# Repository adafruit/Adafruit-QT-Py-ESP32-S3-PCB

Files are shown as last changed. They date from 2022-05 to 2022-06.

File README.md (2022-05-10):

## Adafruit QT Py ESP32-S3 WiFi Dev Board PCB

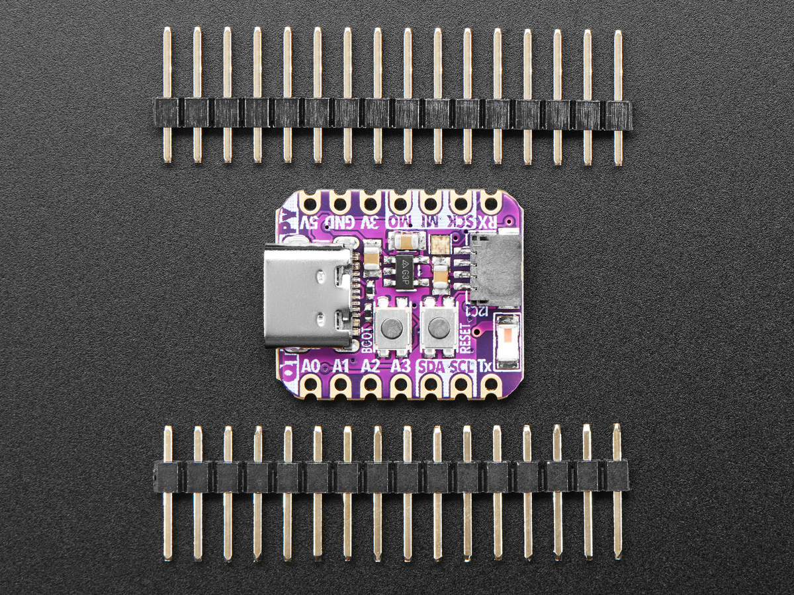
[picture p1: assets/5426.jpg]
<a href="http://www.adafruit.com/products/5426"><br/>
Click here to purchase one from the Adafruit shop</a>

PCB files for the Adafruit QT Py ESP32-S3 WiFi Dev Board. 

Format is EagleCAD schematic and board layout
* https://www.adafruit.com/product/5426

### Description

The ESP32-S3 has arrived in QT Py format - and what a great way to get started with this powerful new chip from Espressif! With dual 240 MHz cores, WiFi and BLE support, and native USB, this QT Py is great for powering your IoT projects.

The ESP32-S3 is a highly-integrated, low-power, 2.4 GHz Wi-Fi System-on-Chip (SoC) solution that now has WiFi and BLE support, built-in native USB as well as some other interesting new technologies like Time of Flight distance measurements. With its state-of-the-art power and RF performance, this SoC is an ideal choice for a wide variety of application scenarios relating to the Internet of Things (IoT), wearable electronics, and smart homes. 

With native USB and 8 MB Flash this board will let you upgrade your existing ESP32 projects. Native USB means it can act like a keyboard or a disk drive, and no external USB-to-Serial converter required. WiFi and BLE mean it's awesome for IoT projects.

OLEDs! Inertial Measurement Units! Sensors a-plenty. All plug-and-play thanks to the innovative chainable design: SparkFun Qwiic-compatible STEMMA QT connectors for the I2C bus so you don't even need to solder! Just plug in a compatible cable and attach it to your MCU of choice, and you’re ready to load up some software and measure some light. Seeed Grove I2C boards will also work with this adapter cable.

Pinout and shape are Seeed Xiao compatible, with castellated pads so you can solder it flat to a PCB. In addition to the QT connector, we also added an RGB NeoPixel (with controllable power pin to allow for ultra-low-power usage), a reset button (great for restarting your program or entering the bootloader), and a button on GPIO 0 for entering the ROM bootloader or for user input

The ESP32-S3 has a dual-core 240 MHz chip, so it is comparable to ESP32's dual-core. However, there is no Bluetooth Classic support, only Bluetooth LE. This chip is a great step up from the earlier ESP32-S2! This ESP32-S3 chip we are using on the QT Py comes with 8 MB flash and no PSRAM, but it does have 512KB of SRAM so its fine for use with CircuitPython support as long as massive buffers are not needed. It's also great for use in ESP-IDF or with Arduino support.

* Same size, form-factor, and pin-out as Seeed Xiao
* USB Type C connector - If you have only Micro B cables, this adapter will come in handy!
* ESP32-S3 Dual Core 240MHz Tensilica processor - the next generation of ESP32-Sx, with native USB so it can act like a keyboard/mouse, MIDI device, disk drive, etc!
* Comes with 8MB Flash, 512KB SRAM, no PSRAM
* Native USB supported by every OS - can be used in Arduino or CircuitPython as USB serial console, MIDI, Keyboard/Mouse HID, even a little disk drive for storing Python scripts.
* Can be used with Arduino IDE or CircuitPython
* Built-in RGB NeoPixel LED with power control to reduce quiescent power in deep sleep
* Battery input pads on underside with diode protection for external battery packs up to 6V input
* 13 GPIO pins:
    * 11 on breakout pads, 2 more on QT connector
    * 10 x 12-bit analog inputs (SPI high speed pads do not have analog inputs)
    * PWM outputs on any pin
    * Two I2C ports, one on the breakout pads, and another with STEMMA QT plug-n-play connector
    * Hardware UART
    * Hardware SPI on the high speed SPI peripheral pins
    * Hardware I2S on any pins
    * 5 x Capacitive Touch with no additional components required
* 3.3V regulator with 600mA peak output
* Light sleep at 2~4mA, deep sleep at ~70uA
* Reset switch for starting your project code over, boot 0 button for entering bootloader mode
* Really really small

### License

Adafruit invests time and resources providing this open source design, please support Adafruit and open-source hardware by purchasing products from [Adafruit](https://www.adafruit.com)!

Designed by Limor Fried/Ladyada for Adafruit Industries.

Creative Commons Attribution/Share-Alike, all text above must be included in any redistribution. 
See license.txt for additional details.

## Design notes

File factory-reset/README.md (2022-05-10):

## Factory Reset file - QT ESP32-S3 WiFi Dev Board

This is the factory reset file for the QT ESP32-S3 WiFi Dev Board.

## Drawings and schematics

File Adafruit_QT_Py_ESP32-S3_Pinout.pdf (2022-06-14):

# Adafruit QT Py ESP32S3

# https://www.adafruit.com/5426

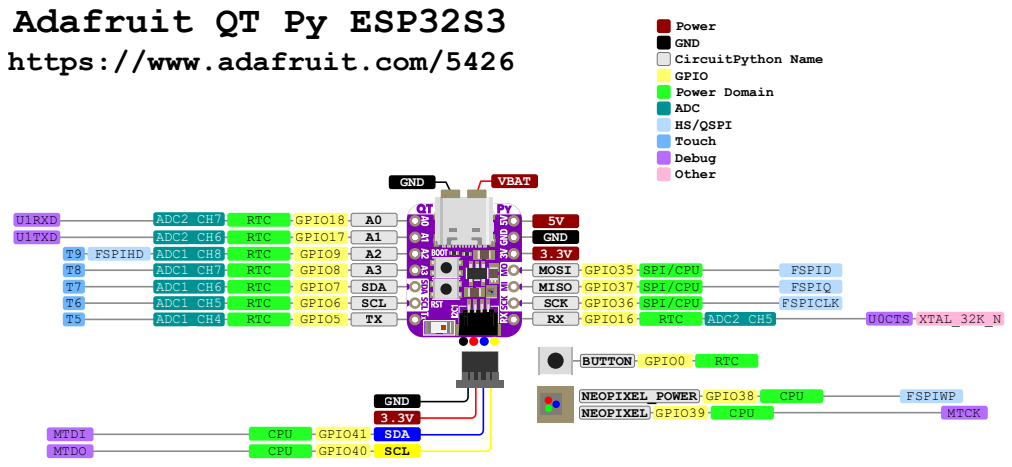
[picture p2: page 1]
U1RXD; ADC2_CH7 RTC GPIO18 A0; ADC1_CH4 RTC; GPIO5 TX; RX GPIO16 RTC ADC2_CH5; U0CTS XTAL_32K_N; GND 3.3V; MOSI GPIO35 SPI/CPU; FSPID; MISO GPIO37 SPI/CPU; FSPIQ; SCK GPIO36 SPI/CPU; FSPICLK; MTDI; CPU GPIO41; U1TXD; ADC2_CH6 RTC GPIO17 A1; T9 FSPIHD ADC1_CH8 RTC; GPIO9 A2; ADC1_CH7 RTC; GPIO8 A3; ADC1_CH6 RTC; GPIO7 SDA; ADC1_CH5 RTC; GPIO6 SCL; BUTTON GPIO0; RTC; NEOPIXEL_POWER GPIO38 CPU; FSPIWP; NEOPIXEL GPIO39 CPU; MTCK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

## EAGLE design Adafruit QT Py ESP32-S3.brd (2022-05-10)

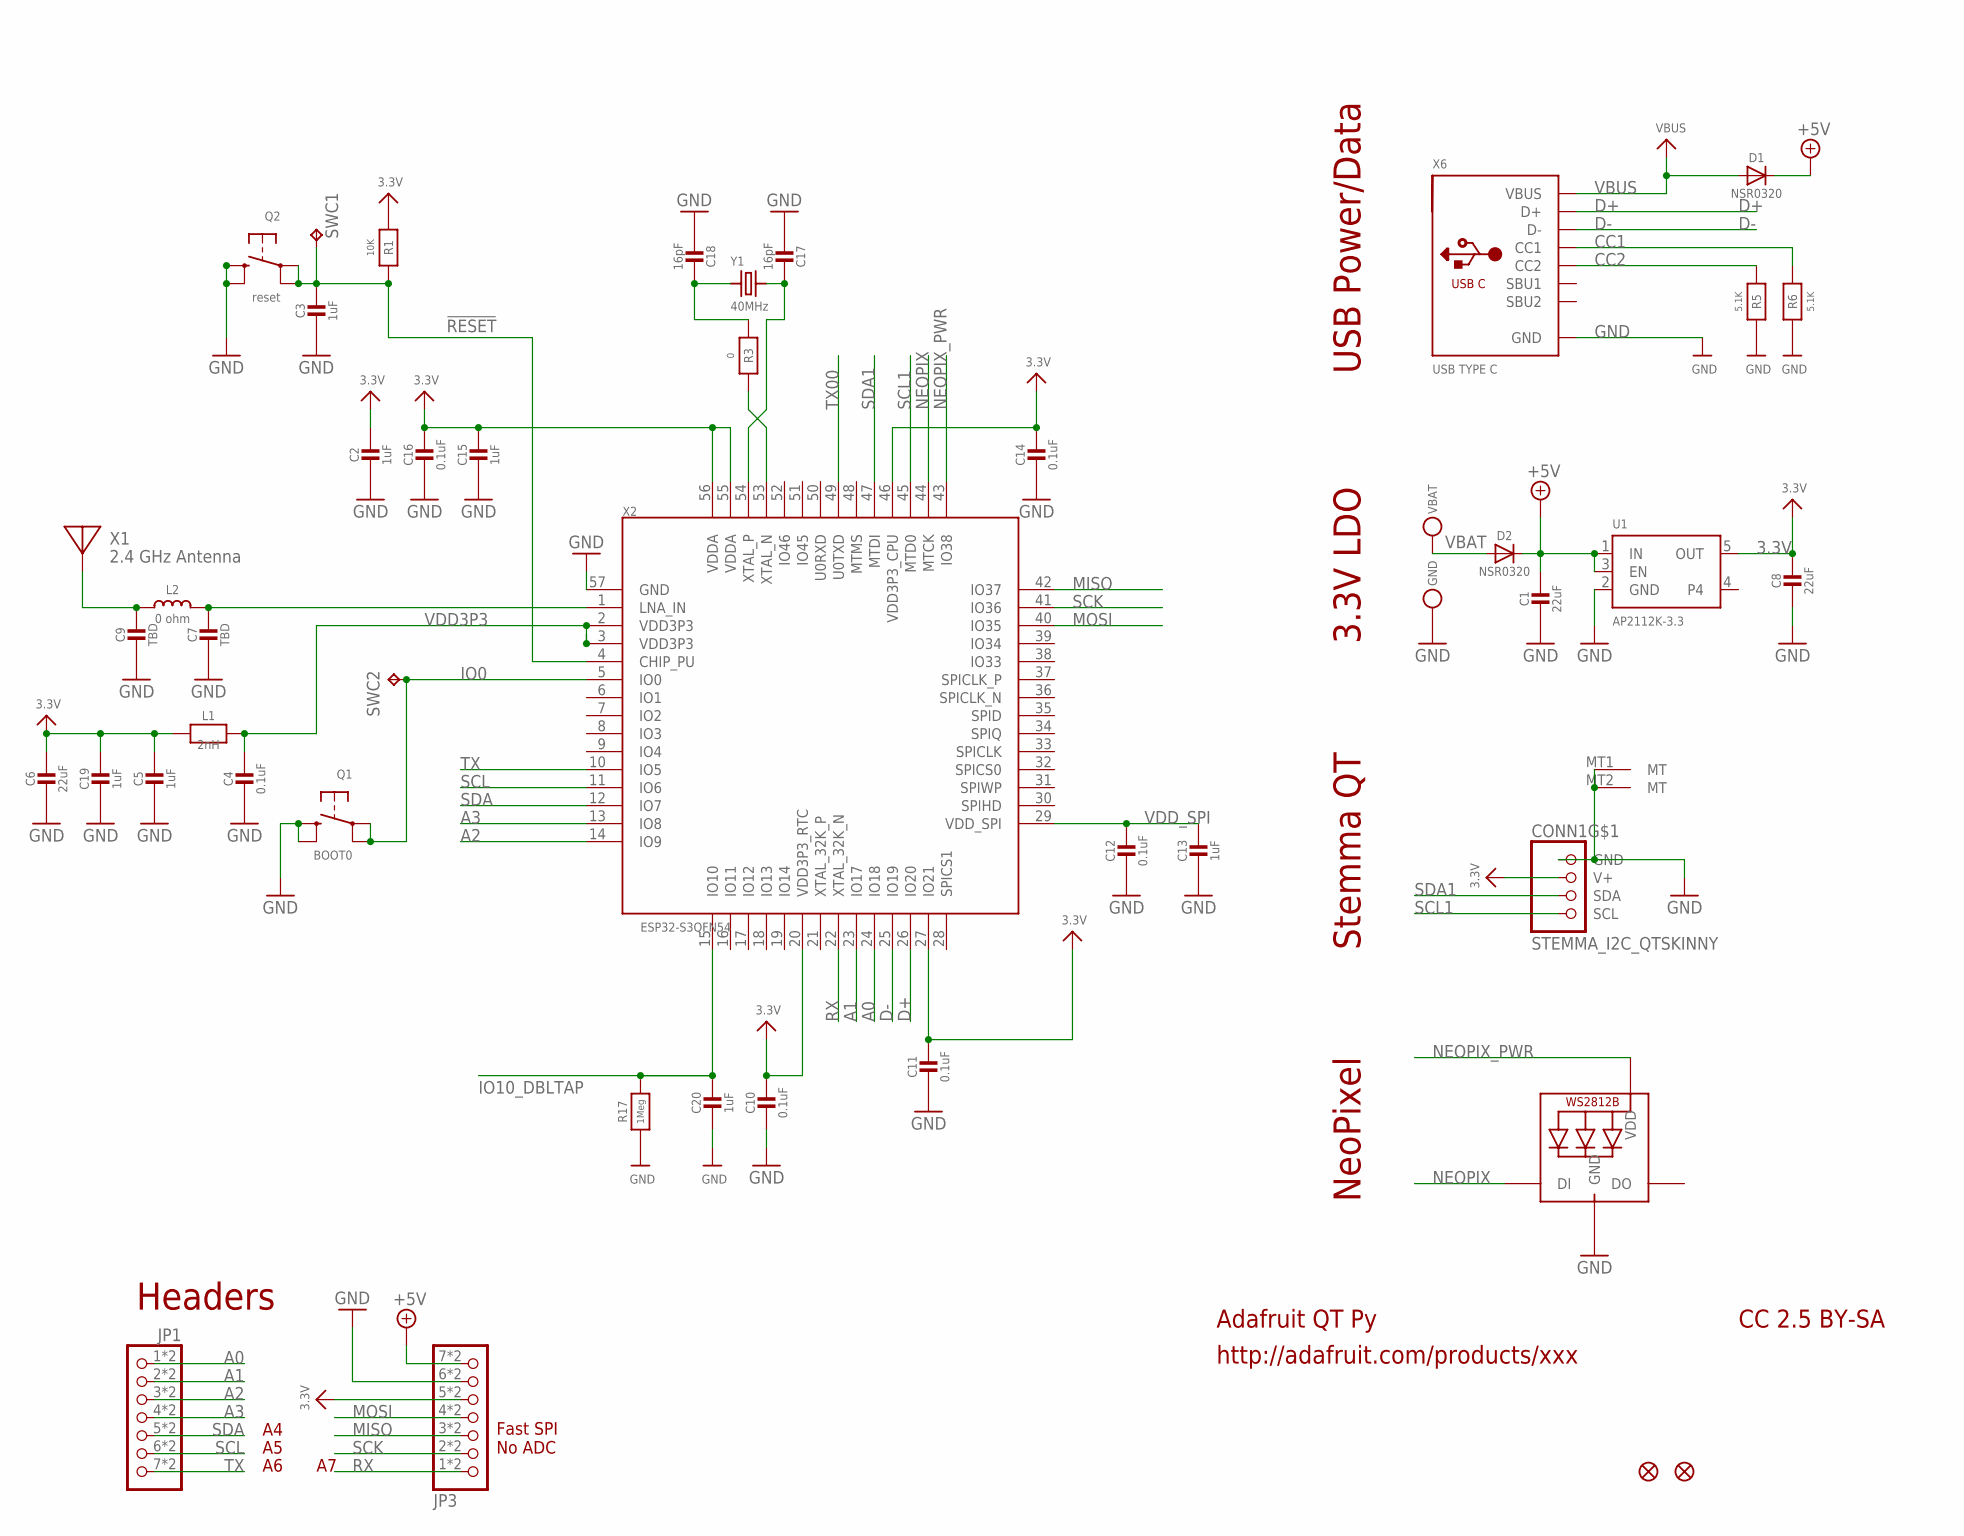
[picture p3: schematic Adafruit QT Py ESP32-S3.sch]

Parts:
C1, C6, C8: 22uF; 0805-NO
C2, C3, C5, C13, C15, C19, C20: 1uF; _0402NO
C4, C10, C11, C12, C14, C16: 0.1uF; _0402NO
C7, C9: TBD; _0402NO
C17, C18: 16pF; _0402NO
CONN1: STEMMA_I2C_QTSKINNY; JST_SH4_SKINNY
D1, D2: NSR0320; SOD-323_MINI
GND: TESTPOINT_MINUS; TESTPOINT_MINUS_1X3MM
JP1, JP3: HEADER-1X7_CASTEL; 1X07_CASTEL
L1: 2nH; _0402NO
L2: 0 ohm; _0402
LED1: WS2812B_SK6805_1515; SK6805_1515
Q1: BOOT0; BTN_KMR2_4.6X2.8
Q2: reset; BTN_KMR2_4.6X2.8
R1: 10K; _0402NO
R3: 0; _0402NO
R5, R6: 5.1K; _0402NO
R17: 1Meg; _0402NO
SWC1, SWC2: TPB1,27; B1,27
U1: AP2112K-3.3; SOT23-5
U$6, U$8: FIDUCIAL_1MM
VBAT: TESTPOINT_PLUS13; TESTPOINT_PLUS_1X3MM
X1: 2.4 GHz Antenna; ANT_2450AT18B100
X2: ESP32-S3QFN54; QFN56_7X7
X6: USB TYPE C; USB_C_CUSB31-CFM2AX-01-X
Y1: 40MHz; CRYSTAL_2X1.6

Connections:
3.3V: C2.1, C5.1, C6.1, C8.1, C10.1, C11.1, C14.1, C15.1, C16.1, C19.1, CONN1.2 (V+), JP3.5, JP3.5C (5), L1.1, R1.1, U1.5 (OUT), X2.20 (VDD3P3_RTC), X2.27 (IO21), X2.46 (VDD3P3_CPU), X2.55 (VDDA), X2.56 (VDDA)
!RESET: C3.1, Q2.A, Q2.A' (P1), R1.2, SWC1.TP, X2.4 (CHIP_PU)
+5V: C1.1, D1.C, D2.C, JP3.7, JP3.7C (7), U1.1 (IN), U1.3 (EN)
A0: JP1.1, JP1.1C (1), X2.24 (IO18)
A1: JP1.2, JP1.2C (2), X2.23 (IO17)
A2: JP1.3, JP1.3C (3), X2.14 (IO9)
A3: JP1.4, JP1.4C (4), X2.13 (IO8)
CC1: R6.2, X6.A5 (CC1)
CC2: R5.2, X6.B5 (CC2)
D+: X2.26 (IO20), X6.A6 (D+), X6.B6 (D+)
D-: X2.25 (IO19), X6.A7 (D-), X6.B7 (D-)
GND: C1.2, C2.2, C3.2, C4.2, C5.2, C6.2, C7.2, C8.2, C9.2, C10.2, C11.2, C12.2, C13.2, C14.2, C15.2, C16.2, C17.2, C18.2, C19.2, C20.2, CONN1.1 (GND), CONN1.MT1 (MT), CONN1.MT2 (MT), GND.P$1, JP3.6, JP3.6C (6), LED1.4 (GND), Q1.B (S), Q1.B' (S1), Q2.B (S), Q2.B' (S1), R5.1, R6.1, R17.1, U1.2 (GND), X2.57 (GND), X6.A1B12 (GND), X6.B1A12 (GND)
IO0: Q1.A, Q1.A' (P1), SWC2.TP, X2.5 (IO0)
IO10_DBLTAP: C20.1, R17.2, X2.15 (IO10)
MISO: JP3.3, JP3.3C (3), X2.42 (IO37)
MOSI: JP3.4, JP3.4C (4), X2.40 (IO35)
unnamed: R3.2, X2.53 (XTAL_N)
unnamed: C7.1, L2.2, X2.1 (LNA_IN)
unnamed: C9.1, L2.1, X1.FP
unnamed: C17.1, X2.54 (XTAL_P), Y1.3 (2)
unnamed: C18.1, R3.1, Y1.1
NEOPIX: LED1.1 (DI), X2.44 (MTCK)
NEOPIX_PWR: LED1.2 (VDD), X2.43 (IO38)
RX: JP3.1, JP3.1C (1), X2.22 (XTAL_32K_N)
SCK: JP3.2, JP3.2C (2), X2.41 (IO36)
SCL: JP1.6, JP1.6C (6), X2.11 (IO6)
SCL1: CONN1.4 (SCL), X2.45 (MTD0)
SDA: JP1.5, JP1.5C (5), X2.12 (IO7)
SDA1: CONN1.3 (SDA), X2.47 (MTDI)
TX: JP1.7, JP1.7C (7), X2.10 (IO5)
TX00: X2.49 (U0TXD)
VBAT: D2.A, VBAT.P$1
VBUS: D1.A, X6.A4B9 (VBUS), X6.B4A9 (VBUS)
VDD3P3: C4.1, L1.2, X2.2 (VDD3P3), X2.3 (VDD3P3)
VDD_SPI: C12.1, C13.1, X2.29 (VDD_SPI)

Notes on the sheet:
Adafruit QT Py
http://adafruit.com/products/xxx
CC 2.5 BY-SA
NeoPixel
Stemma QT
3.3V LDO
USB Power/Data
Headers
Fast SPI No ADC

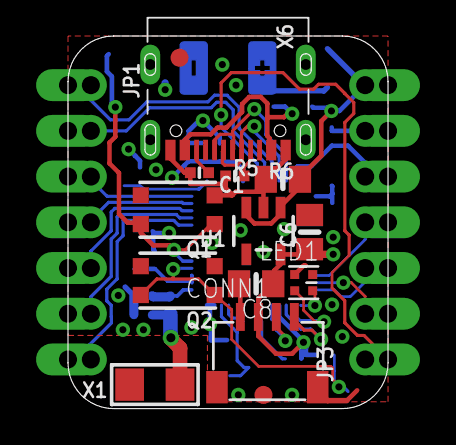
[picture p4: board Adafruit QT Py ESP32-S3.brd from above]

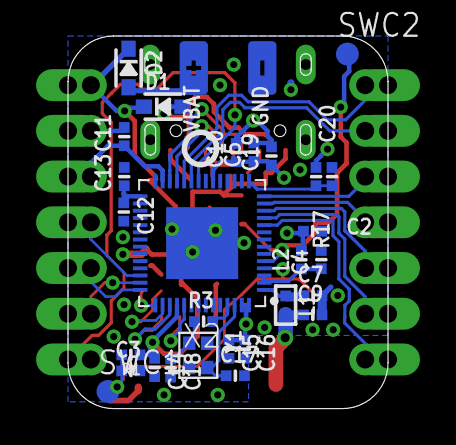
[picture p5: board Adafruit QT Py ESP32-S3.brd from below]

Board: 4 copper layers, 17.8 x 20.7 mm, 49 parts (32 on the bottom side), 34 nets.

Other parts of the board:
U$7: QTPY_ESP32_TOP
U$11: QTPYS3_BOT
U$12: PCBFEAT-REV-040

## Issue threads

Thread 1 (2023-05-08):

add 3d model

s-light, 2023-05-08:
is it possible to add a 3d model ?
maybe directly exported from eagle?

i think this are the needed details:

- board outline
- usb-c connector position and outline/height
- STEMMA QT connector position and outline/height
- button positions/height
- battery solder-pad positions
- neopixel position/height

[adafruit forum post](https://forums.adafruit.com/viewtopic.php?t=201244)

caternuson, 2023-05-08:
This guides covers how to generate 3D files from the Eagle files:
https://learn.adafruit.com/how-to-convert-eagle-pcbs-to-3d-models-in-fusion-360

Closed 2023-05-08.

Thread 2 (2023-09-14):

C19,C20 value

pallavi199427, 2023-09-14:
I am currently working on a project that involves the use of your schematic as a reference. However, I have encountered an issue where the values for capacitors C19 and C20 are not declared or specified in the schematic. This lack of information is causing some uncertainty and hindering my progress in replicating and understanding the circuit.

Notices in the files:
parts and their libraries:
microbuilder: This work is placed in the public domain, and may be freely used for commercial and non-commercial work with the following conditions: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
